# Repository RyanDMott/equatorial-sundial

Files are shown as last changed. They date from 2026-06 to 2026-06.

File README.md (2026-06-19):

# Equatorial Sphere-Shadow Sundial

A parametric 3D-printable sundial and companion analemma engraving,
generated with OpenSCAD and Python.

---

## Files

| File | Purpose |
|---|---|
| `solar.py` | Equation of Time and solar declination functions |
| `demo_analemma.py` | Generates the analemma plot and OpenSCAD data file |
| `analemma_2030.scad` | Auto-generated data: 365 × (EoT, declination) pairs for 2030 |
| `analemma_groove.scad` | OpenSCAD module: analemma figure-eight groove for engraving |
| `equatorial_sundial.scad` | Main sundial body |

---

## Prerequisites

**Python 3** with matplotlib:
```
pip install matplotlib
```

**OpenSCAD** 2021.01 or later: https://openscad.org/downloads.html

---

## Running the scripts

### 1. Generate the analemma data and plot

```
python3 demo_analemma.py
```

This writes two files:
- `analemma_plot.png` — a colour-coded figure-eight plot of the analemma for 2030
- `analemma_2030.scad` — the data file consumed by `analemma_groove.scad`

To generate data for a different year, change `YEAR = 2030` near the top of
`demo_analemma.py` and re-run.  Rename the output `.scad` file and update the
`include` line in `analemma_groove.scad` to match.

### 2. Render the sundial in OpenSCAD

Open `equatorial_sundial.scad` in OpenSCAD and set the parameters at the top
of the file for your location:

```openscad
latitude         = 50.11;   // degrees North (negative for South)
longitude        = 14.44;   // degrees East  (negative for West)
time_now         = 14;      // your local time, 24-hour
time_gmt         = 13;      // current time in GMT (UTC+0; same as London time in winter)
is_daylight_saving = false; // true if your time_now is DST
```

Press **F6** to render, then export as STL for printing.

### 3. Render the analemma groove

Place `analemma_2030.scad` and `analemma_groove.scad` in the same directory,
then open `analemma_groove.scad` in OpenSCAD and press **F6**.

By default it renders `analemma_demo_slab()` — a flat tile with the groove
already cut in.  To use the groove as a cutter in your own design instead,
replace the last line with:

```openscad
analemma_groove();
```

---

## Setting up and reading the sundial

### Orientation

The sundial is an **equatorial** design: its annular ring sits parallel to
Earth's equator when flat its base at the printed latitude.

1. Place the sundial base on a level surface.
   The top cut should be level with the horizon.
2. Orient the whole assembly so the support arc behind the annulus
   points toward true North (Northern Hemisphere) or true South (Southern Hemisphere).  
   Use a compass and correct for **magnetic declination** for your location.
   The inside of the annulus should face the equator.

### Reading the time

The small central sphere casts a shadow onto the inside of the annular ring.
Read the hour number nearest the centre of the shadow. 
The annular ring's facet edges mark the top of each hour.
Use the lower set of engraved numbers if clocks are on daylight saving time.

### Converting to clock time

Earth's elliptical orbit and axial tilt mean the sun runs up to ~16 minutes
fast or slow relative to a perfect clock throughout the year.
A timelapse video of photos at noon across a whole year would show 
the sun's shadow tracing a figure eight from top in winter to bottom in summer
centered on the 12:00 line but offset up to 16 minutes from it.
The analemma boss on the base encodes this offset (shown for Northern Hemisphere):

- The **x axis** (left–right) represents the EoT in minutes at the same scale as the sundial.
  Positive x (right) means the shadow is fast/ahead — subtract those minutes.
  Negative x (left) means the shadow is slow/behind — add those minutes.
- The **y axis** (up–down) represents solar declination (the sun's
  apparent latitude), ranging from −23.4° (winter solstice) to
  +23.4° (summer solstice).  This axis lets you locate today's date on
  the curve. 

**To find today's correction:**
1. Estimate today's position on the figure-eight: narrow lobe = northern summer,
   wider lobe = northern winter, and the arrowhead on January 1 shows which way
   the date progresses.
2. Read the x position of that point on the curve.  
3. Add or subtract that distance from the sundial reading, to get standard clock time.  

### Additional readings

 - The shadow's vertical location indicates time of year. The shadow ranges from
   * the bottom edge at the summer solstice
   * the top edge at the winter solstice
   * the middle crease at spring and autumn equinoxes
   Note that the transition from standard to Daylight Saving time does not generally
   happen at equinoxes. But in general, if the shadow is well into the top half,
   you should probably read the upper set of numbers, and vice-versa.
 - The ring is cut off at the horizon such that the shadow reaches the edge
   at sunrise and sunset. 

For example, suppose the shadow is approaching the top of a northern sundial and lies near the facet edge between the "1" and the "2" but closer to the "2". The corresponding lower numbers are "2" and "3" but are not used near winter. The shadow lies 25% of the way across the "2" facet so it looks like it reads "2:15" and late autumn. However the rising side of the top of the analemma curve  (behind the arrow) shows the shadow is shifted about 25% of a facet to the right. So subtract 15 minutes from the shadow and read "2:00".

With the same time on a southern sundial in the same time zone but in the southern hemisphere, the shadow will fall near the bottom of the sundial between the "3" and the "2". In this case the "3" and "2" are closer and summer "Daylight Saving" time should be used if the local time uses a summer offset. In this orientation the analemma curve is wider at the bottom, and because the shadow has been falling we read the left side of the curve and know the shadow is shifted 15 minutes to the left. Because southern sundials advance from right in the morning to left in the evening, this still means subtracting 15 minutes from the time, leaving us with "3:00".

---

## How it works (brief)

The annular ring has the same tilt as Earth's equator relative to your
horizon, so the sun sweeps across it at a constant angular rate of 15°/hour
regardless of season.  The sphere's shadow therefore always falls on the
correct hour line — no seasonal correction is needed for the ring itself.

The hour markings are pre-rotated so that 12 o'clock is directly between
you and the sun at apparent solar noon, and adjusted for your time zone
offset relative to London (UTC) at render time.  A second set of markings
offset by one face (15°) is engraved on the underside for daylight saving
reference.

## Extension ideas
 - Cut grooves at the facet edges to make the grid more visible.
 - Check southern hemisphere logic

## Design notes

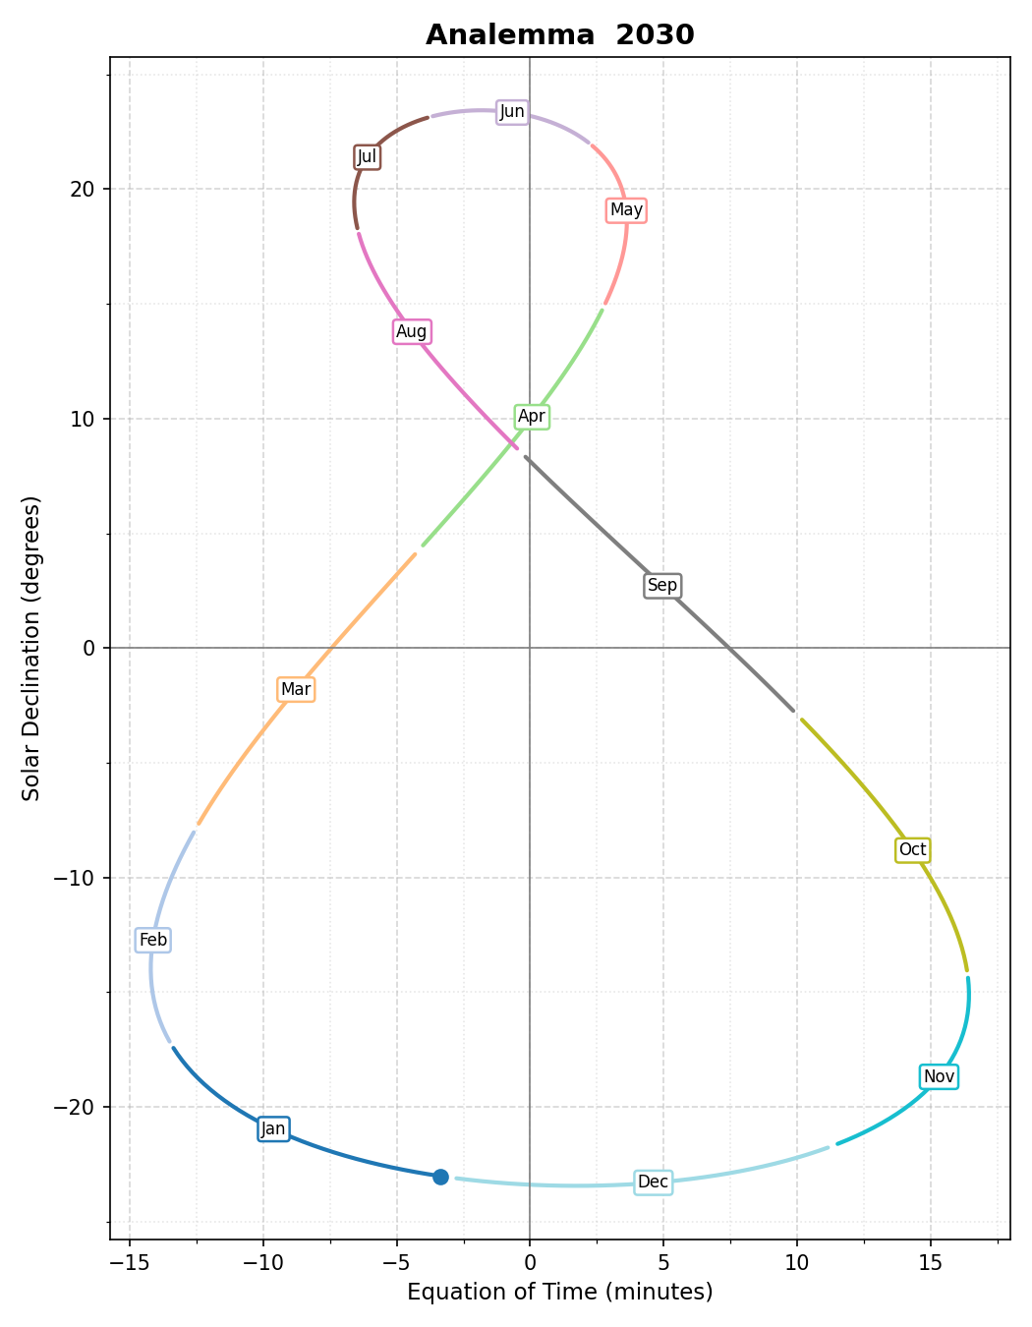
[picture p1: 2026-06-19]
analemma_plot.png

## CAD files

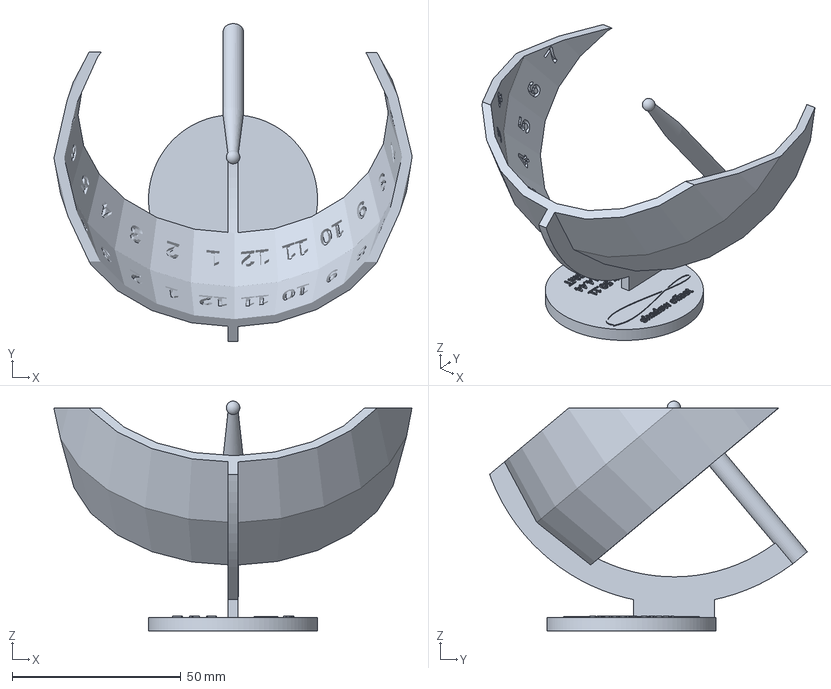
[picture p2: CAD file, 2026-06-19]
equatorial_sundial.3mf
105.9 x 94.0 x 68.0 mm

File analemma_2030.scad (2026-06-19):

// analemma_2030.scad  –  auto-generated by demo_analemma.py
// Year: 2030
// 365 entries, index 0 = Jan 1.  Each entry: [eot_minutes, declination_degrees]
// Usage in OpenSCAD:
//   include <analemma_2030.scad>
//   eot  = ANALEMMA_DATA[day_index][0];
//   decl = ANALEMMA_DATA[day_index][1];

ANALEMMA_DATA = [
    [-3.3582, -23.0118],  // day   1
    [-3.8283, -22.9270],  // day   2
    [-4.2926, -22.8345],  // day   3
    [-4.7508, -22.7345],  // day   4
    [-5.2023, -22.6269],  // day   5
    [-5.6466, -22.5119],  // day   6
    [-6.0833, -22.3895],  // day   7
    [-6.5119, -22.2597],  // day   8
    [-6.9320, -22.1226],  // day   9
    [-7.3432, -21.9783],  // day  10
    [-7.7450, -21.8269],  // day  11
    [-8.1371, -21.6684],  // day  12
    [-8.5191, -21.5029],  // day  13
    [-8.8906, -21.3304],  // day  14
    [-9.2514, -21.1511],  // day  15
    [-9.6011, -20.9651],  // day  16
    [-9.9394, -20.7724],  // day  17
    [-10.2660, -20.5731],  // day  18
    [-10.5807, -20.3673],  // day  19
    [-10.8831, -20.1551],  // day  20
    [-11.1732, -19.9366],  // day  21
    [-11.4507, -19.7119],  // day  22
    [-11.7154, -19.4811],  // day  23
    [-11.9672, -19.2443],  // day  24
    [-12.2059, -19.0015],  // day  25
    [-12.4313, -18.7530],  // day  26
    [-12.6434, -18.4988],  // day  27
    [-12.8421, -18.2390],  // day  28
    [-13.0273, -17.9737],  // day  29
    [-13.1990, -17.7031],  // day  30
    [-13.3571, -17.4272],  // day  31
    [-13.5016, -17.1461],  // day  32
    [-13.6324, -16.8600],  // day  33
    [-13.7497, -16.5690],  // day  34
    [-13.8535, -16.2732],  // day  35
    [-13.9437, -15.9726],  // day  36
    [-14.0204, -15.6675],  // day  37
    [-14.0838, -15.3579],  // day  38
    [-14.1340, -15.0440],  // day  39
    [-14.1709, -14.7258],  // day  40
    [-14.1948, -14.4036],  // day  41
    [-14.2057, -14.0773],  // day  42
    [-14.2039, -13.7471],  // day  43
    [-14.1894, -13.4131],  // day  44
    [-14.1625, -13.0755],  // day  45
    [-14.1233, -12.7344],  // day  46
    [-14.0721, -12.3898],  // day  47
    [-14.0089, -12.0419],  // day  48
    [-13.9341, -11.6908],  // day  49
    [-13.8478, -11.3366],  // day  50
    [-13.7503, -10.9795],  // day  51
    [-13.6419, -10.6195],  // day  52
    [-13.5227, -10.2568],  // day  53
    [-13.3930, -9.8914],  // day  54
    [-13.2531, -9.5236],  // day  55
    [-13.1033, -9.1533],  // day  56
    [-12.9438, -8.7808],  // day  57
    [-12.7749, -8.4060],  // day  58
    [-12.5969, -8.0293],  // day  59
    [-12.4101, -7.6505],  // day  60
    [-12.2148, -7.2699],  // day  61
    [-12.0114, -6.8876],  // day  62
    [-11.8000, -6.5037],  // day  63
    [-11.5810, -6.1183],  // day  64
    [-11.3548, -5.7314],  // day  65
    [-11.1217, -5.3433],  // day  66
    [-10.8819, -4.9540],  // day  67
    [-10.6359, -4.5635],  // day  68
    [-10.3839, -4.1722],  // day  69
    [-10.1262, -3.7799],  // day  70
    [-9.8633, -3.3869],  // day  71
    [-9.5954, -2.9932],  // day  72
    [-9.3229, -2.5990],  // day  73
    [-9.0461, -2.2043],  // day  74
    [-8.7653, -1.8093],  // day  75
    [-8.4810, -1.4140],  // day  76
    [-8.1934, -1.0186],  // day  77
    [-7.9028, -0.6231],  // day  78
    [-7.6097, -0.2277],  // day  79
    [-7.3144, +0.1675],  // day  80
    [-7.0171, +0.5625],  // day  81
    [-6.7183, +0.9571],  // day  82
    [-6.4182, +1.3512],  // day  83
    [-6.1173, +1.7448],  // day  84
    [-5.8158, +2.1377],  // day  85
    [-5.5141, +2.5298],  // day  86
    [-5.2125, +2.9211],  // day  87
    [-4.9114, +3.3114],  // day  88
    [-4.6110, +3.7007],  // day  89
    [-4.3118, +4.0888],  // day  90
    [-4.0140, +4.4756],  // day  91
    [-3.7179, +4.8611],  // day  92
    [-3.4239, +5.2452],  // day  93
    [-3.1323, +5.6277],  // day  94
    [-2.8434, +6.0086],  // day  95
    [-2.5575, +6.3877],  // day  96
    [-2.2749, +6.7650],  // day  97
    [-1.9959, +7.1404],  // day  98
    [-1.7209, +7.5138],  // day  99
    [-1.4500, +7.8850],  // day 100
    [-1.1836, +8.2541],  // day 101
    [-0.9219, +8.6208],  // day 102
    [-0.6653, +8.9851],  // day 103
    [-0.4140, +9.3469],  // day 104
    [-0.1683, +9.7062],  // day 105
    [+0.0716, +10.0628],  // day 106
    [+0.3054, +10.4165],  // day 107
    [+0.5329, +10.7675],  // day 108
    [+0.7538, +11.1154],  // day 109
    [+0.9679, +11.4603],  // day 110
    [+1.1750, +11.8021],  // day 111
    [+1.3749, +12.1406],  // day 112
    [+1.5673, +12.4758],  // day 113
    [+1.7520, +12.8075],  // day 114
    [+1.9290, +13.1358],  // day 115
    [+2.0979, +13.4604],  // day 116
    [+2.2586, +13.7814],  // day 117
    [+2.4110, +14.0985],  // day 118
    [+2.5548, +14.4118],  // day 119
    [+2.6900, +14.7212],  // day 120
    [+2.8164, +15.0264],  // day 121
    [+2.9339, +15.3276],  // day 122
    [+3.0423, +15.6245],  // day 123
    [+3.1416, +15.9171],  // day 124
    [+3.2317, +16.2052],  // day 125
    [+3.3125, +16.4889],  // day 126
    [+3.3839, +16.7681],  // day 127
    [+3.4459, +17.0425],  // day 128
    [+3.4984, +17.3122],  // day 129
    [+3.5413, +17.5771],  // day 130
    [+3.5748, +17.8371],  // day 131
    [+3.5987, +18.0921],  // day 132
    [+3.6131, +18.3421],  // day 133
    [+3.6179, +18.5868],  // day 134
    [+3.6133, +18.8264],  // day 135
    [+3.5992, +19.0606],  // day 136
    [+3.5758, +19.2895],  // day 137
    [+3.5430, +19.5129],  // day 138
    [+3.5010, +19.7308],  // day 139
    [+3.4499, +19.9431],  // day 140
    [+3.3898, +20.1497],  // day 141
    [+3.3208, +20.3505],  // day 142
    [+3.2430, +20.5456],  // day 143
    [+3.1566, +20.7347],  // day 144
    [+3.0618, +20.9179],  // day 145
    [+2.9587, +21.0951],  // day 146
    [+2.8476, +21.2663],  // day 147
    [+2.7286, +21.4313],  // day 148
    [+2.6020, +21.5901],  // day 149
    [+2.4679, +21.7427],  // day 150
    [+2.3267, +21.8890],  // day 151
    [+2.1786, +22.0289],  // day 152
    [+2.0238, +22.1625],  // day 153
    [+1.8627, +22.2896],  // day 154
    [+1.6954, +22.4102],  // day 155
    [+1.5224, +22.5242],  // day 156
    [+1.3439, +22.6317],  // day 157
    [+1.1603, +22.7326],  // day 158
    [+0.9719, +22.8268],  // day 159
    [+0.7789, +22.9144],  // day 160
    [+0.5819, +22.9952],  // day 161
    [+0.3810, +23.0692],  // day 162
    [+0.1767, +23.1365],  // day 163
    [-0.0307, +23.1970],  // day 164
    [-0.2407, +23.2507],  // day 165
    [-0.4531, +23.2976],  // day 166
    [-0.6673, +23.3375],  // day 167
    [-0.8832, +23.3707],  // day 168
    [-1.1001, +23.3969],  // day 169
    [-1.3179, +23.4163],  // day 170
    [-1.5360, +23.4288],  // day 171
    [-1.7540, +23.4344],  // day 172
    [-1.9717, +23.4331],  // day 173
    [-2.1885, +23.4249],  // day 174
    [-2.4041, +23.4098],  // day 175
    [-2.6181, +23.3879],  // day 176
    [-2.8302, +23.3591],  // day 177
    [-3.0398, +23.3234],  // day 178
    [-3.2466, +23.2809],  // day 179
    [-3.4504, +23.2317],  // day 180
    [-3.6505, +23.1756],  // day 181
    [-3.8468, +23.1127],  // day 182
    [-4.0389, +23.0432],  // day 183
    [-4.2263, +22.9669],  // day 184
    [-4.4088, +22.8839],  // day 185
    [-4.5860, +22.7943],  // day 186
    [-4.7576, +22.6981],  // day 187
    [-4.9232, +22.5953],  // day 188
    [-5.0825, +22.4861],  // day 189
    [-5.2353, +22.3703],  // day 190
    [-5.3812, +22.2481],  // day 191
    [-5.5200, +22.1195],  // day 192
    [-5.6514, +21.9846],  // day 193
    [-5.7751, +21.8434],  // day 194
    [-5.8909, +21.6960],  // day 195
    [-5.9986, +21.5424],  // day 196
    [-6.0979, +21.3827],  // day 197
    [-6.1886, +21.2169],  // day 198
    [-6.2705, +21.0451],  // day 199
    [-6.3435, +20.8675],  // day 200
    [-6.4073, +20.6839],  // day 201
    [-6.4618, +20.4946],  // day 202
    [-6.5070, +20.2995],  // day 203
    [-6.5425, +20.0988],  // day 204
    [-6.5684, +19.8924],  // day 205
    [-6.5845, +19.6806],  // day 206
    [-6.5907, +19.4633],  // day 207
    [-6.5869, +19.2406],  // day 208
    [-6.5732, +19.0127],  // day 209
    [-6.5493, +18.7795],  // day 210
    [-6.5154, +18.5412],  // day 211
    [-6.4713, +18.2978],  // day 212
    [-6.4171, +18.0494],  // day 213
    [-6.3528, +17.7961],  // day 214
    [-6.2783, +17.5380],  // day 215
    [-6.1938, +17.2752],  // day 216
    [-6.0992, +17.0076],  // day 217
    [-5.9945, +16.7355],  // day 218
    [-5.8800, +16.4589],  // day 219
    [-5.7555, +16.1779],  // day 220
    [-5.6213, +15.8926],  // day 221
    [-5.4774, +15.6030],  // day 222
    [-5.3238, +15.3093],  // day 223
    [-5.1609, +15.0115],  // day 224
    [-4.9886, +14.7097],  // day 225
    [-4.8070, +14.4039],  // day 226
    [-4.6165, +14.0944],  // day 227
    [-4.4170, +13.7812],  // day 228
    [-4.2088, +13.4643],  // day 229
    [-3.9921, +13.1438],  // day 230
    [-3.7670, +12.8199],  // day 231
    [-3.5337, +12.4926],  // day 232
    [-3.2924, +12.1620],  // day 233
    [-3.0434, +11.8282],  // day 234
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

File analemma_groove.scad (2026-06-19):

// analemma_groove.scad
//
// Engraves the analemma curve as a groove on a flat surface.
// The curve is the locus  (x, y) = ( R*sin(EoT*0.25 deg),  R*sin(decl deg) )
// for each day of the year, where EoT is in minutes and decl in degrees.
//
// Requires: analemma_2030.scad  (include'd below)
//
// Public modules:
//   analemma_groove()       - groove + arrowhead as a positive solid
//                             (subtract from your own surface)
//   analemma_demo_slab()    - a rectangular slab with the groove already cut

include <analemma_2030.scad>

// ---------------------------------------------------------------------------
// Parameters
// ---------------------------------------------------------------------------
ANALEMMA_R   = 50;        // projection radius (mm)
GROOVE_WIDTH = 0.5;       // total width of groove (mm)
GROOVE_DEPTH = 0.3;       // depth  of groove (mm)
ARROW_LENGTH = 3;       // arrowhead tip-to-base (mm)
ARROW_WIDTH  = 2;       // arrowhead base width  (mm)

// Demo-slab dimensions
SLAB_HALF_W  = 16;        // half-width  in x (mm)
SLAB_HALF_H  = 28;        // half-height in y (mm)
SLAB_THICK   = 3;         // thickness       (mm)

// ---------------------------------------------------------------------------
// Helpers
// ---------------------------------------------------------------------------

// One ANALEMMA_DATA entry  ->  [x, y] in mm.
// sin() in OpenSCAD takes degrees already.
// EoT is in minutes; * 0.25 converts to degrees.
function analemma_xy(entry) =
    [ ANALEMMA_R * sin(entry[0] * 0.25),
      ANALEMMA_R * sin(entry[1])
    ];

// Contiguous run of [x,y] points, 0-based indices a..b inclusive.
function analemma_points(a, b) =
    [ for (i = [a : b]) analemma_xy(ANALEMMA_DATA[i]) ];

// ---------------------------------------------------------------------------
// Lobe geometry
//
// The analemma self-intersects exactly once, between the segments
// day102->103 and day242->243 (1-based), at approx (-0.15, +7.77) mm.
// Splitting there gives two lobes, each a simple (non-self-intersecting)
// closed curve.  Python brute-force search confirmed zero self-intersections
// in either lobe.
//
// The lobe endpoints (indices 102 and 242) are 0.25 mm apart — well within
// the 0.5 mm groove width — so polygon()'s implicit closing edge is fully
// buried inside the stripe and invisible.
//
//   Lobe 1 (lower, wraps through January):
//       indices 242 .. 364, then 0 .. 102
//   Lobe 2 (upper):
//       indices 102 .. 242
//
// Each lobe is turned into a stripe via the standard dilate-minus-erode
// idiom:
//       difference() {
//           offset(+GROOVE_WIDTH/2)  polygon(lobe_points);
//           offset(-GROOVE_WIDTH/2)  polygon(lobe_points);
//       }
// This is well-defined because both lobes have nonzero area and the
// erosion (0.25 mm) is much smaller than any feature size.
// ---------------------------------------------------------------------------

function lobe1_points() = concat(analemma_points(242, 364),
                                 analemma_points(0,   102));
function lobe2_points() = analemma_points(102, 242);

// ---------------------------------------------------------------------------
// Groove lobe – dilate-minus-erode stripe, extruded to groove depth
// ---------------------------------------------------------------------------
module groove_lobe(pts) {
    linear_extrude(height = GROOVE_DEPTH)
        difference() {
            offset(r = +GROOVE_WIDTH / 2)  polygon(pts);
            offset(r = -GROOVE_WIDTH / 2)  polygon(pts);
        }
}

// ---------------------------------------------------------------------------
// Arrowhead at Jan 1 (index 0), pointing toward Jan 2 (index 1).
//
// Triangle in a local frame where +Y is "forward", rotated into world
// coords and translated to the Jan-1 point.  Extruded to groove depth.
// ---------------------------------------------------------------------------

module analemma_arrowhead() {
    i0 = 0;
    i1 = 15; // HACK lookahead ~ arrowhead length instead of one day
    p0 = analemma_xy(ANALEMMA_DATA[i0]);
    p1 = analemma_xy(ANALEMMA_DATA[i1]);

    dx = p1[0] - p0[0];
    dy = p1[1] - p0[1];
    // atan2(x, y) -> angle from +Y toward +X, exactly what rotate([0,0,a])
    // needs to map local +Y onto the (dx, dy) tangent.
    angle = atan2(dx, dy);

    translate([p0[0], p0[1], 0])
        rotate([0, 0, -angle])
            linear_extrude(height = GROOVE_DEPTH)
                polygon([
                    [ 0,                ARROW_LENGTH ],   // tip
                    [-ARROW_WIDTH / 2,  0            ],   // base left
                    [ ARROW_WIDTH / 2,  0            ]    // base right
                ]);
}

// ---------------------------------------------------------------------------
// Public: complete groove + arrowhead (positive solid).
//   Sits on z = 0, extrudes in +z.  Subtract from a surface whose top
//   face is at z = 0.
// ---------------------------------------------------------------------------
module analemma_groove() {
    union() {
        groove_lobe(lobe1_points());
        groove_lobe(lobe2_points());
        analemma_arrowhead();
    }
}

// ---------------------------------------------------------------------------
// Demo slab – a plain block with the groove cut into its top face.
// ---------------------------------------------------------------------------
module analemma_demo_slab() {
    difference() {
        // Slab: top face flush at z = 0
        translate([0, 0, -SLAB_THICK/2])
            cube([2*SLAB_HALF_W, 2*SLAB_HALF_H, SLAB_THICK], center = true);

        // Groove cuts downward from z = 0
        translate([0, 0, -0.01])
        analemma_groove();
    }
}

// ---------------------------------------------------------------------------
// Default render – the demo slab.
// Swap to  analemma_groove();  if you only need the cutter shape.
// ---------------------------------------------------------------------------
analemma_demo_slab();

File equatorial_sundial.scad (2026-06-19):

// Equatorial Sundial - Parametric design for 3D printing
// The annulus is aligned with Earth's equator, and a sphere casts shadows to indicate time

use <analemma_groove.scad>

// ===== INPUT PARAMETERS =====
latitude = 51.5 * 0 + 0 * 10 + 1 * 50.11;           // Latitude of location (degrees, positive = North)
longitude = -0.1 * 0 + 14.44 * 1;         // Longitude of location (degrees, positive = East)
time_now = 4 * 0 + 1 * 2;             // Current local time (24-hour format)
time_gmt = 1 * 0;          // Current Greenwich Mean Time (24-hour format)
is_daylight_saving = true; // Is time_now daylight saving time?

// ===== DESIGN PARAMETERS =====
earth_tilt = 23.44;        // Earth's axial tilt in degrees
inner_radius = 50;         // Inner radius of annulus in mm
annulus_thickness = 3;     // Radial thickness of annulus
segments = 24;             // Number of segments (24 for hours)
sphere_radius = 2;         // Fixed radius of central sphere in mm

// Text parameters
text_height = 2;           // Embossing depth for numbers
text_size = 6;             // Size of hour numbers

// Support structure parameters
support_width = 8;         // Width of support arc
support_thickness = 3;     // Thickness of support arc
shaft_radius_top = sphere_radius * 0.7;  // Radius at sphere (30% smaller than sphere)
shaft_radius_mid = 3;      // Radius of main shaft
shaft_taper_fraction = 1/3; // Fraction of shaft that is tapered
base_disc_radius = inner_radius * 0.5;     // Radius of base disc
base_disc_thickness = 4;   // Thickness of base disc
spacer_height = 16;        // Raise above the base disc 

// ===== DERIVED PARAMETERS =====
outer_radius = inner_radius + annulus_thickness;

is_northern = latitude > 0;

// Calculate time offset (hours difference between local time and London)
effective_time_now = time_now - (is_daylight_saving ? 1 : 0);
time_offset = ( effective_time_now - time_gmt + 12 ) % 24 - 12;

// Hour angle rotation (counterclockwise for time ahead of London)
hour_angle = time_offset * 15; // 15 degrees per hour (360/24)

// Rotation for longitude (annulus rotates about z-axis)
// Start with edge center at 0° longitude aligned with x-axis
longitude_rotation = - longitude;

// outer radius of support arc
support_radius = inner_radius + support_width;

// Height to reach earth_tilt elevation with half-angle cone
solstice_height = inner_radius * sin(earth_tilt);

// shift base towards center of mass. Close except near equator?
base_offset_abs = inner_radius * 0.25;
base_offset = base_offset_abs * ( is_northern ? 1 : - 1 );
spacer_length = 2 * ( base_disc_radius - base_offset_abs ) - 1;

// ===== HELPER MODULES =====

// Create annulus using cone subtraction method
module annulus() {
    // Cone slope is half of earth_tilt
    cone_angle = earth_tilt / 2;
    
    inner_height = solstice_height + 0.2; // Add small amount to avoid z-fighting
    
    difference() {
        // Outer cones - cut at earth_tilt elevation
        union() {
            // Upper cone (0° to earth_tilt elevation)
            cylinder(h = solstice_height, 
                    r1 = outer_radius, 
                    r2 = outer_radius - solstice_height * tan(cone_angle), 
                    $fn = segments);
            
            // Lower cone (0° to -earth_tilt elevation)
            rotate([180, 0, 0])
                cylinder(h = solstice_height, 
                        r1 = outer_radius, 
                        r2 = outer_radius - solstice_height * tan(cone_angle), 
                        $fn = segments);
        }
        
        // Inner cones (to create hollow annulus) - also cut at earth_tilt elevation
        union() {
            // Upper cone - extend slightly to avoid z-fighting
            cylinder(h = inner_height, 
                    r1 = inner_radius, 
                    r2 = inner_radius - inner_height * tan(cone_angle), 
                    $fn = segments);
            
            // Lower cone - extend slightly to avoid z-fighting
            translate([0, 0, 0.1]) // Offset to avoid z-fighting at bottom
                rotate([180, 0, 0])
                    cylinder(h = inner_height+0.2, 
                            r1 = inner_radius, 
                            r2 = inner_radius - inner_height * tan(cone_angle), 
                            $fn = segments);
        }
    }
}

// Add hour numbers embossed on annulus face
module hour_numbers(top_face = true, rotation_offset = 0) {
    // Cone angle for tilting text
    cone_angle = earth_tilt / 2;
    
    for (hour = [1:12]) {
        for (cycle = [0:1]) {
            // Calculate angle for this hour (starting from 0° = x-axis edge center)
            // Rotate counterclockwise (when viewed from +z) for increasing hours
            angle = -((hour ) + cycle * 12) * (360 / segments) + rotation_offset - (360 / segments / 2);
            
            // Calculate radial position on the inner surface
            r = inner_radius * cos(earth_tilt / 2);
            
            // Calculate vertical position based on face
            z_pos = top_face ? 
                r * tan(earth_tilt / 2) : 
                -r * tan(earth_tilt / 2);
            
            // Position and orient the text
            rotate([0, 0, angle])
                translate([r, 0, z_pos])
                    rotate([0, top_face ? -cone_angle : cone_angle, 0]) // Tilt radially into surface
                        rotate([90, 0, 90])
                            rotate([0, 0, (latitude < 0) ? 180 : 0]) // Flip for southern hemisphere
                                rotate([0, 180, 0])
                                    linear_extrude(height = 3 * text_height)
                                        text(str(hour), size = text_size, halign = "center", valign = "center", font = "Liberation Sans:style=Bold");
        }
    }
}

// Support arc connecting sphere to annulus
module support_arc() {
    // Create a disc section in the x-z plane
    difference() {
        // Outer disc
        rotate([90, 0, 0])
            cylinder(h = support_thickness, r = support_radius, center = true, $fn = 100);
        
        // Cut out middle to avoid z-fighting
        rotate([90, 0, 0])
            cylinder(h = support_thickness + 2*support_width, r = inner_radius, center = true, $fn = 100);
        
        // Select quadrant based on latitude
        if (latitude >= 0) {
            // Keep lower +x quadrant for positive latitude
            translate([0, 0, 100 + solstice_height])
                cube([200, 200, 200], center = true); // Remove upper half
            translate([-100, 0, 0])
                cube([200, 200, 200], center = true); // Remove -x half
        } else {
            // Keep upper +x quadrant for negative latitude
            translate([0, 0, -100 - solstice_height])
                cube([200, 200, 200], center = true); // Remove lower half
            translate([-100, 0, 0])
                cube([200, 200, 200], center = true); // Remove -x half
        }
    }
}

// Tapered shaft connecting sphere to support arc
module support_shaft() {
    // Calculate arc radius to match support_arc
    arc_radius = inner_radius - inner_radius * tan(earth_tilt) * tan(earth_tilt / 2);
    shaft_length = support_radius;
    taper_length = shaft_length * shaft_taper_fraction;
    straight_length = shaft_length - taper_length;
    
    translate([0, 0, -shaft_length]) {
        // Tapered section (top 1/3 nearest sphere)
        translate([0, 0, straight_length])
            cylinder(h = taper_length, r1 = shaft_radius_mid, r2 = shaft_radius_top, $fn = 32);
        
        // Straight section (bottom 2/3)
        cylinder(h = straight_length, r = shaft_radius_mid, $fn = 32);
    }
}
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

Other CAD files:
equatorial_sundial.stl

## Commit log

2026-06-19 First prompt draft Claude Sonnet 3.5 and response
    [equatorial_sundial.scad]
2026-06-19 First edit to get it to compile
    [equatorial_sundial.scad]
2026-06-19 First rewrite
    [equatorial_sundial.scad]
2026-06-19 Last LLM draft
    [equatorial_sundial.scad]
2026-06-19 Hand edits
    - still don't quite get the right sunrise/sunset times
    [equatorial_sundial.scad]
2026-06-19 Latitude fix
    [equatorial_sundial.scad]
2026-06-19 Smaller base
    [equatorial_sundial.scad]
2026-06-19 Claude generated analemma plot for 2030 and apparently vetted it
    [analemma_2030.scad]
2026-06-19 First attempt at engraving
    [analemma_groove.scad]
2026-06-19 Switch to lobe outlines and emboss
    [analemma_groove.scad, equatorial_sundial.scad]
2026-06-19 Fix latitude flipped, fix london vs GMT, add spacer
    [equatorial_sundial.scad]
2026-06-19 Fix and enlarge arrow
    [analemma_groove.scad]
2026-06-19 Add export of Prague
    [equatorial_sundial.stl]
2026-06-19 Add 3mf with Prague color demo
    [equatorial_sundial.3mf]
2026-06-19 Fix southern hemisphere.
    [equatorial_sundial.scad]
